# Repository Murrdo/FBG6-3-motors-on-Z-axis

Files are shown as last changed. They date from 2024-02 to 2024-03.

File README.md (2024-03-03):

# FBG6-3-motors-on-Z-axis

<details>
  <summary>Фото  (<i>click to expand</i>)</summary>
  <!-- have to be followed by an empty line! -->








</details>

Крепление 2х дополнительных моторов оси Z на FBG6.
<br>Доработанный подвал без ящика в папке basement
<br>Сборка:
<br>1.Печать разметочных моделей креплений к столу
<br>2.Разметка отверстий в столе и нарезание резьбы М3
<br>3.Разметка центрального отверстия вала мотора
<br>4.Разметка крепежных отверстий моторов
<br>Двигатели устанавливаются через проставку, что бы не было потерь области печати по оси Z.
<br>Винты к моторам установлены через пружинные муфты (с преварительным натягом пружины перед фиксацией), на концах валов овальная выточка, между валом двигателей и винтами установлены шарики от подшипников диметром ~5мм

<br>Я печатал из pa6-GF30 хватит ли прочности а АБСа для креплений - неизвестно.

И честно-откровенно о результатах, что реально даёт эта доработка:
<br>1.Большие ускорения по Z (у меня при движках в стелсе потолок скорости 40-45, в спреде намного больше, но "шипение" движков передаётся на раму, ускорения Z - 1.2к без дфектов при поостоянных z-hop'ах, можно до 2-2.5к но торможения становяться очень шумными). Рабочие скорости снятия меша - ускорения 1.2, скорость X/Y - 300, Z - 25.
<br>2.Намного более быстрое снятие меша
<br>3.Эстетически-техническое "наслаждение" работой Z-Tilt и быстрого снятия меша. xD

<br>Как бы всё) Никаких дефектов печати это не решает (во всяком случае я с ними не сталкивался), т.к. изначальной жесткости стала в общем то достаточно. Это никак не сказывается на графиках, болтанке по Z на графике IS по Y, никак не влияет на частоты/размерности.
<br>Ожиданий от этой доработки у меня было много, но они не оправдались, в общем имхо эта доработка из разряда энтузиазма - повод повозиться с принтером и как бы сделать его немного "технологичней".

Конфиг только для примера
```
[z_tilt]
z_positions: 115, 290
	-15, -3
	235, -15
points: 130, 208
	20, 33
	240, 33
speed: 300
horizontal_move_z: 3
retries: 10
retry_tolerance: 0.02
```

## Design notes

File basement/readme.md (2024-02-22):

Автор изначальноно подвала - Dr_Frankenstein76, огромное спасибо ему за исходники)



front_left_leg_sample.stl - модель для разметки отверстий креплений левой передней ножки, можно напечатать целиком что бы примерить с собранными решетками, или только 1-2мм что бы закрепить на стоковое отверстие под ножку для разметки. 



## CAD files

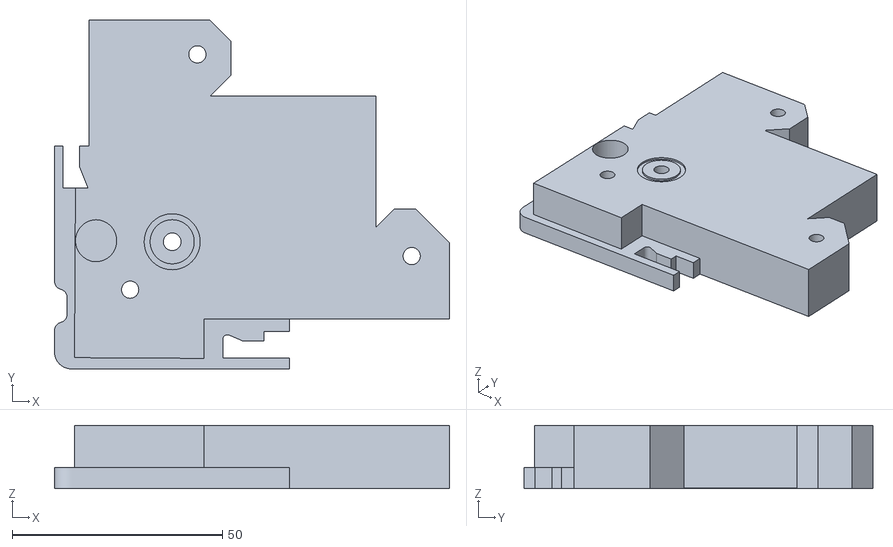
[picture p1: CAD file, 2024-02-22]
basement/front_left_leg_sample.stl
94.0 x 83.0 x 15.0

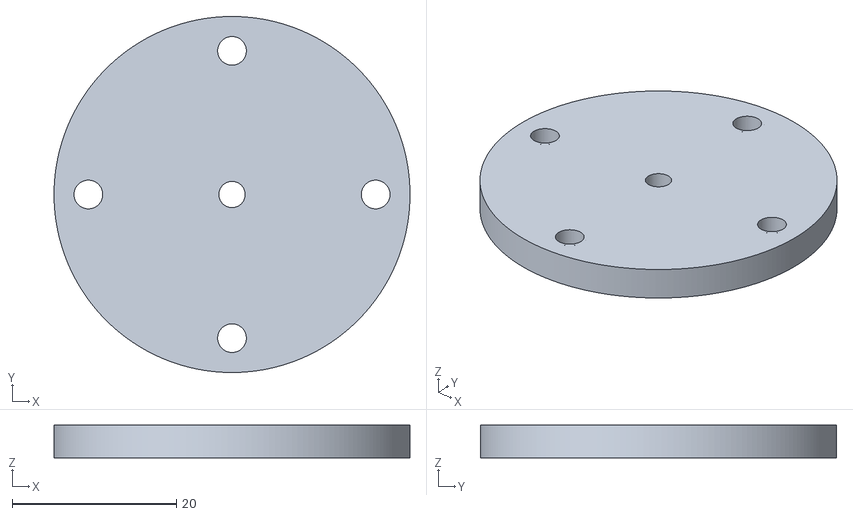
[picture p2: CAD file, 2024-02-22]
basement/leg(x3).stl
43.4 x 43.4 x 4.01

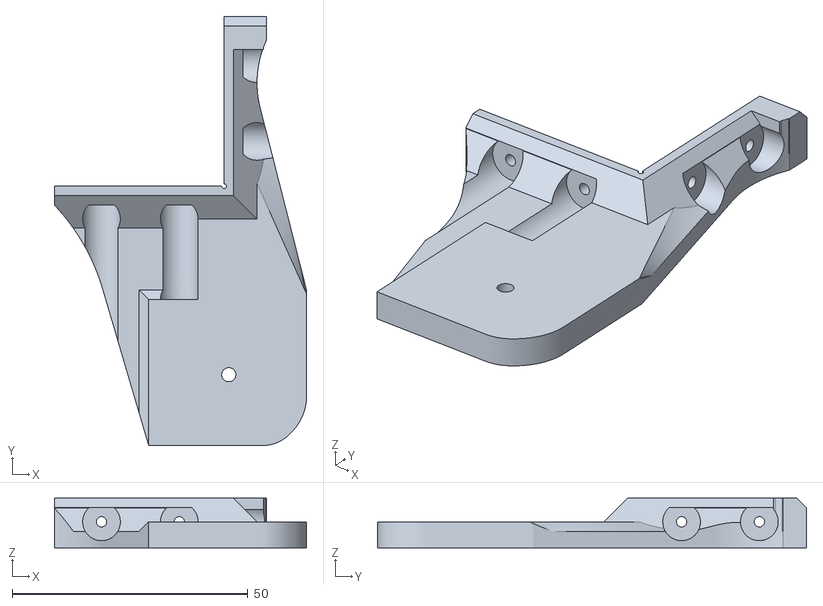
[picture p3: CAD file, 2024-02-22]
motors/marking_right.stl
53.5 x 91.0 x 10.5

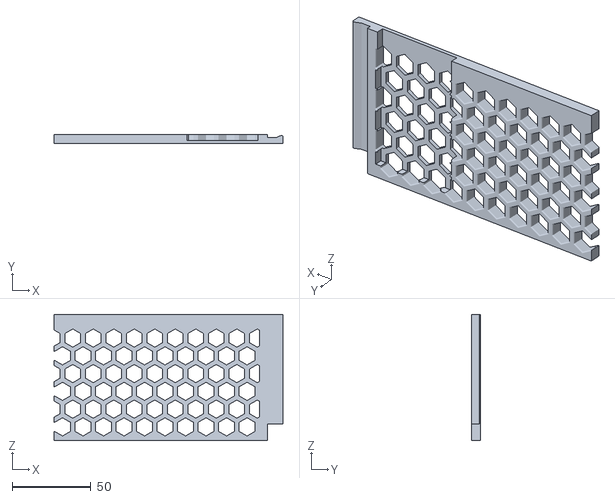
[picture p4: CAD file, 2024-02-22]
basement/front_right(6).stl
145.2 x 6.00 x 80.0

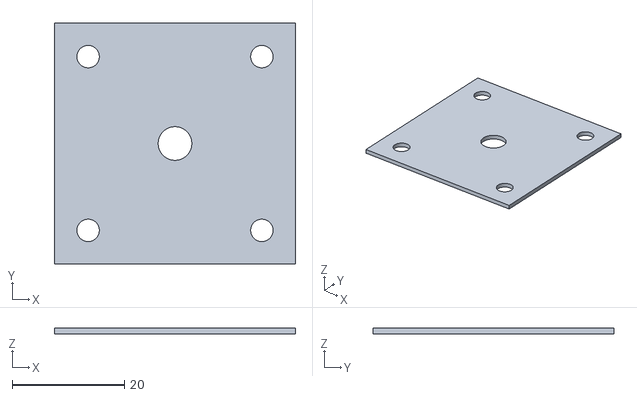
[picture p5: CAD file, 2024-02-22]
motors/marking_nema17.stl
43.0 x 43.0 x 1.00

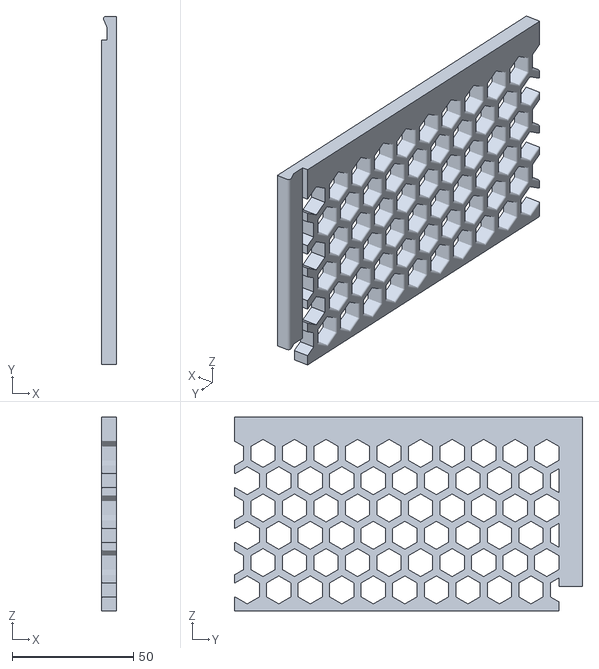
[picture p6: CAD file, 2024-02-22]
basement/left_back(3).stl
6.00 x 143.6 x 80.0

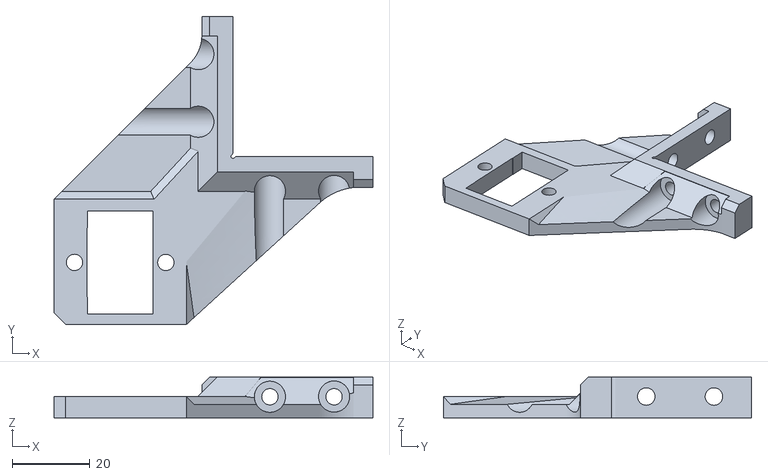
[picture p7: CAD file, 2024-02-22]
motors/final_left.stl
82.0 x 79.2 x 10.5

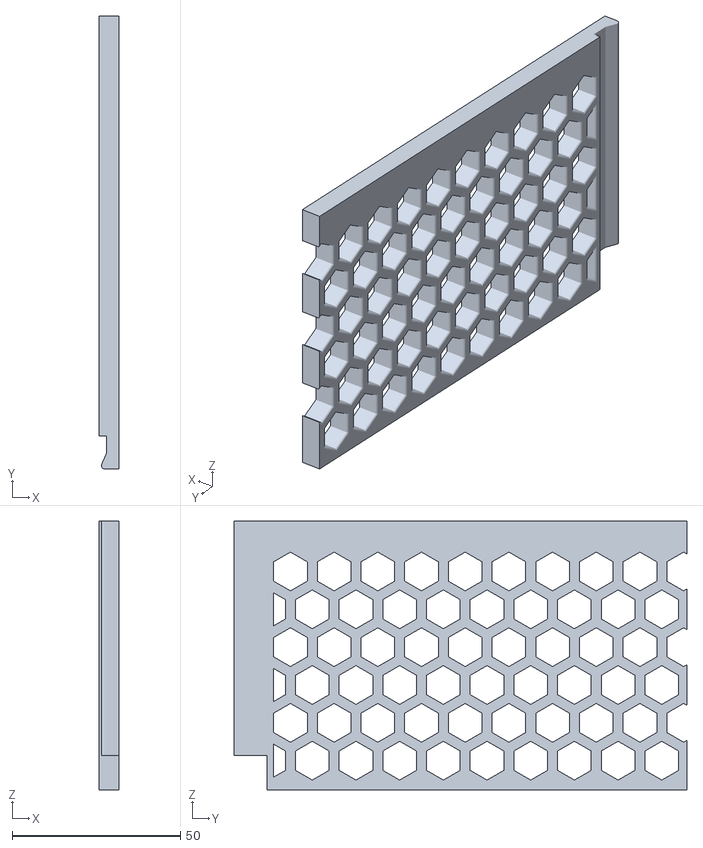
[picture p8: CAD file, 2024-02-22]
basement/left_front(4).stl
6.00 x 134.8 x 80.0

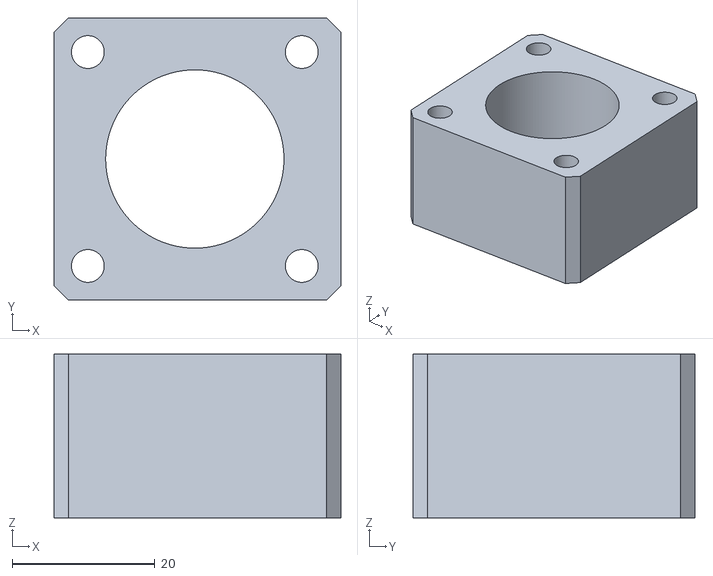
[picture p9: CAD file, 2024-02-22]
motors/motor_spacer.stl
40.2 x 39.5 x 23.0

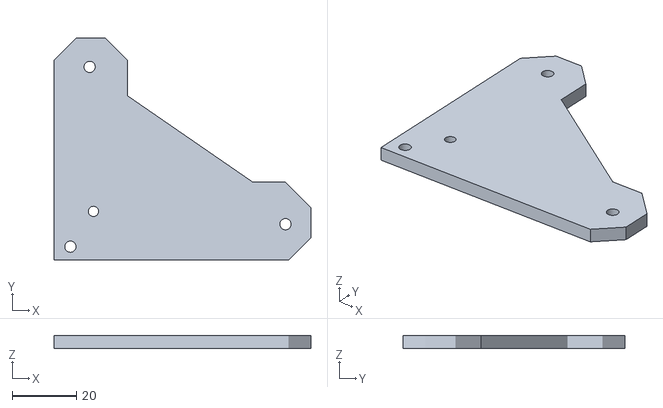
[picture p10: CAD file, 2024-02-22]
basement/leg_left_front(x1).stl
80.1 x 69.3 x 4.00

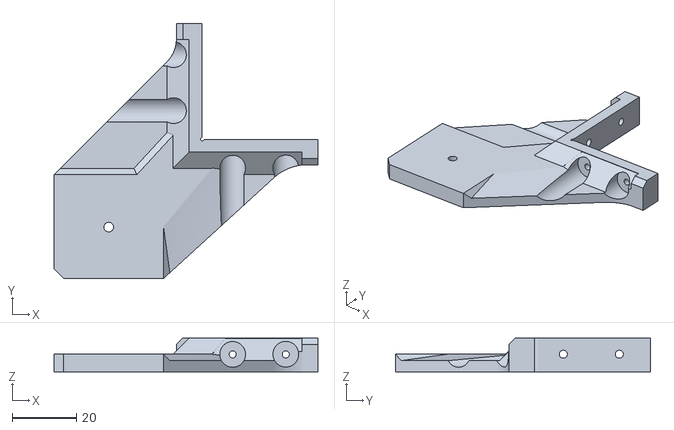
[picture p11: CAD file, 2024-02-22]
motors/marking_left.stl
82.0 x 79.2 x 10.5

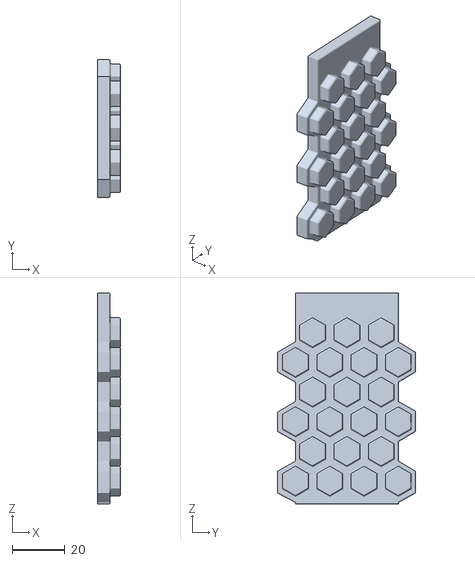
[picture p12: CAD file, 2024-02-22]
basement/connector(x4).stl
8.86 x 52.3 x 80.0

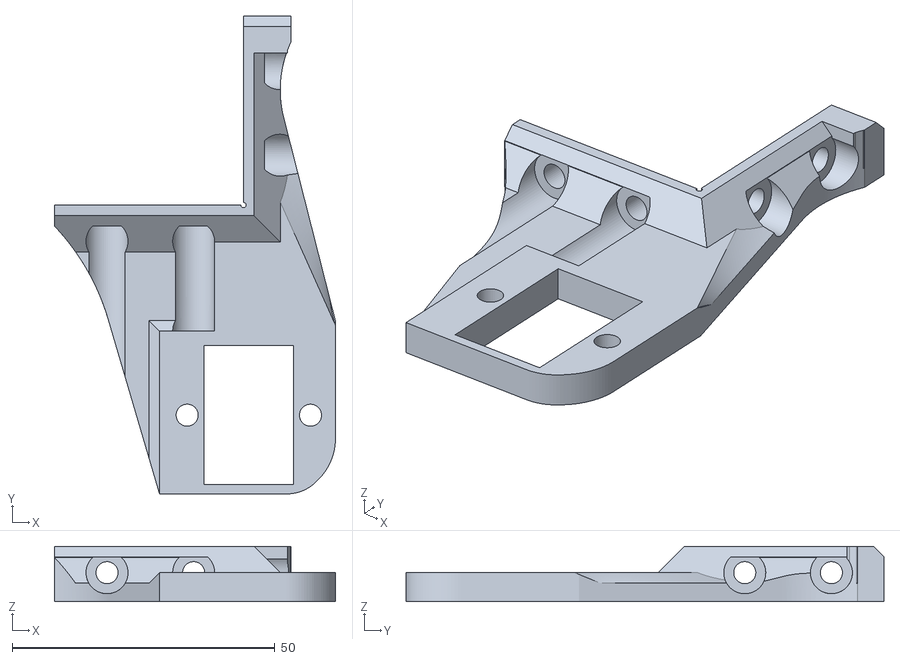
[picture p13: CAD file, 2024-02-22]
motors/final_right.stl
53.5 x 91.0 x 10.5

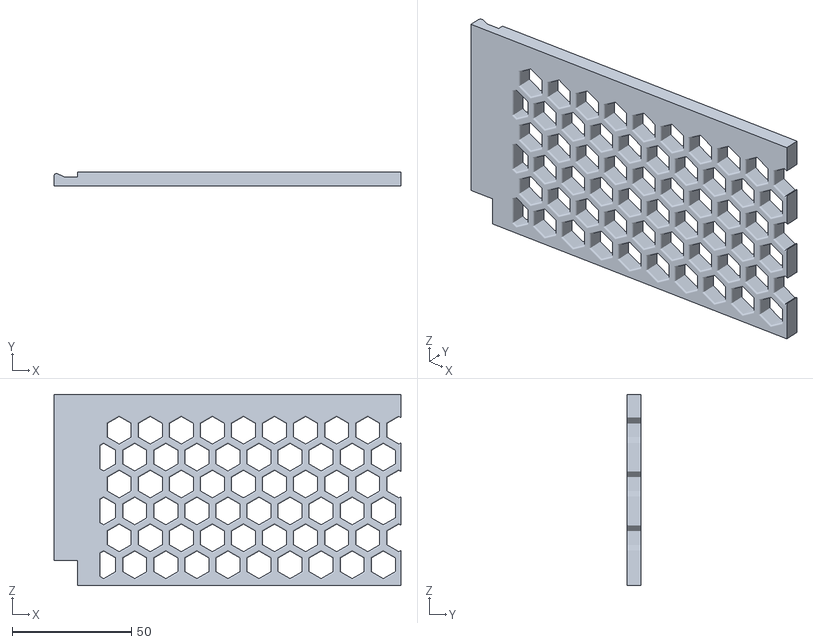
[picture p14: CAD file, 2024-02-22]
basement/front_left(7).stl
145.2 x 6.00 x 80.0

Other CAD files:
basement/Back_right(1).stl
basement/back_left_leg(11).stl
basement/front_right_leg(5).stl
basement/back_right_leg(2).stl
basement/back_left(12).stl
basement/front_left_leg(8).stl
basement/left_back(10).stl
basement/left_front(9).stl
motors/nut_holder.stl
